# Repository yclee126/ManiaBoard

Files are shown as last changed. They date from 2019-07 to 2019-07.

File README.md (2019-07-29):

ManiaBoard (Osu! Keyboard)
==========================

A multi-functional gaming keyboard.

This has been for over a year before uploaded here(and everywhere else), and still WIP.

..For that reason, the code become really massive and finally filled up 99% of Pro Micro's storage. Ah, great.

Uses Arduino Pro Micro(Arduino Leonardo), WS2812B LED strip, Kalih Sockets.



Arduino's usb socket become loose over time with my intense gameplay and it caused occasional disconnection.
So I decided to use jumper wires instead until the next build. Yes, I'm lazy.

Features
--------

- 6 Keys + 2 Function keys
  - Simultaneous input up to 12 keys (Keyboard.h library modified)
  - 700Hz polling rate on average
  - Fast assembly-level pin reading
  - Fast debouncing
- Kalih Socket mount
  - Exchangeable Cherry keys
- Custom Keycaps
  - Lightweight and durable
- LED for each 6 keys
  - 4 different LED modes
  - Fast data transfer code
- KPS Calculation (Keys Per Second)
  - Up to 600 KPS
  - Fast integer time calculation
  - Max KPS indication
- Multiple Keymaps
  - With distinct LED color
- Built-in CUI Menu
  - Coder-friendly menu code
  - Change key mapping
  - Manage keymap slots
  - Multilingual menu (WIP)
  
Manual
------

1. Controls
```
          +----+----+
 (Arduino)| K1 | K2 | K7
+----+----+----+----+
| K3 | K4 | K5 | K6 | K8
+----+----+----+----+
```
- K1 - K6
  - Normal Keys
- K7 : Function Key 1
  - Short : K7
  - Long : Reset KPS display(K2 LED)
- K8 : Function Key 2
  - Short : K8
  - Long : Cycle keymaps
- K7 & K8
  - Short : Enter settings (open cmd or any text editor to print)
  - Long : Cycle LED mode

2. CUI Menu

Press K7 & K8 briefly to enter the setup.
Open cmd or any text editor program to print.
```
          +----+----+
 (Arduino)| UP |    |
+----+----+----+----+
|    | BK | DN | OK |
+----+----+----+----+
```
 - UP : Up
   - Move up from current menu
   - Increase value
 - DN : Down
   - Move down from current menu
   - Decrease value
 - BK : Back
   - Exit from current menu
   - Cancel operation (WIP)
 - OK : Ok
   - Go into selected menu
   - Confirm

Hold UP or DN for fast control.

3. LED Modes

The below map indicates which LED mode is set when it's cycling.

e.g. K6 LED is lit = Mode 4

Press and hold K7 & K8 to cycle.
```
          +----+----+
 (Arduino)|    |    |
+----+----+----+----+
| M1 | M2 | M3 | M4 |
+----+----+----+----+
```
 - Mode 1 : Bright Mode
   - *Colorful!*
     - Shows current KPS if not pressed
     - Shows invert of current color if pressed
     - K2 LED as Max KPS indicator
 - Mode 2 : Dark Mode
   - *Economic lighting.*
     - Shows nothing if not pressed (except for K2)
     - Shows current KPS if pressed
     - K2 LED as Max KPS indicator
 - Mode 3 : Mood Mode
   - *Just the feeling.*
     - Shows nothing if pressed or not (except for K2)
     - K2 LED as Max KPS indicator, but without the flash effect
 - Mode 4 : Stealth Mode
   - *Only you and your monitor.*
     - Shows nothing if pressed or not
     - But Max KPS is still being calculated (displayed on the settings menu)
   
LED shows current keymap color when it's cycling keymaps, regardless of which LED mode is set.

Parts
-----
 - 1 * Arduino Pro Micro
 - 6 * Kalih sockets
 - 6 * Transparent Cherry MX switches
 - 2 * Push buttons
 - 4 * M4 x 12.5mm Screws
   - Or in any length between 11.5mm and 13mm
 - 4 * M4 lock nuts
 - 1 * WS2812B LED strip (6 LEDs)
 - 1 * 330ohm Resistor
 - 1 * 100uF Capacitor (5V and up)
 - 2 * 10pin Pin header socket
 - 1 * PCB piece about size of arduino
 
 The screws and nuts can be gathered from 과학상자("Science Box") kit.

Schematic
---------
```
Dxx = Arduino digital Pin number
[KS] = Kalih Socket
[PB] = Push Button
330R = 330ohm resistor
100uF = 100uF capacitor

        GND
         |
D02-[KS]-+  //K1
	 |
D03-[KS]-+  //K2
	 |
D04-[KS]-+  //K3
	 |
D05-[KS]-+  //K4
	 |
D06-[KS]-+  //K5
	 |
D07-[KS]-+  //K6
	 |
D14-[PB]-+  //K7
	 |
D15-[PB]-+  //K8
         |
	 |  ############################
         +--gnd                        #
D10-330R----din  WS2812B Strip (6LEDs) #
         +--vin                        #
	 |  ############################
         |
	+5V--100uF--GND
```

TODO
----

- Complete the menu
- Optimize everything
- Make Thumb key for 5K maps
- Make right hand keyboard for 10K maps
- Find a better way to display KPS

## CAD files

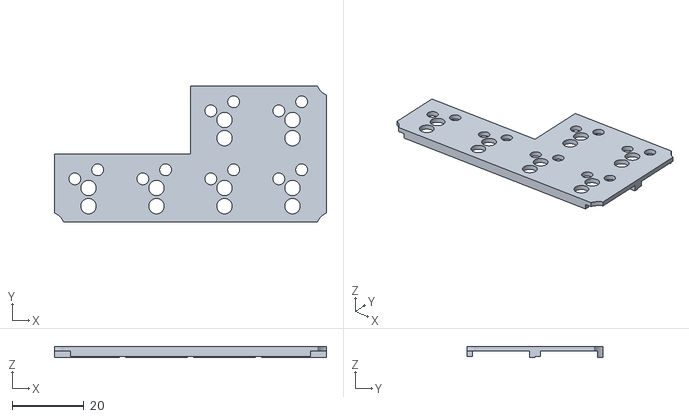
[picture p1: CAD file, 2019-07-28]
Model/frame.stl
76.0 x 38.0 x 3.15

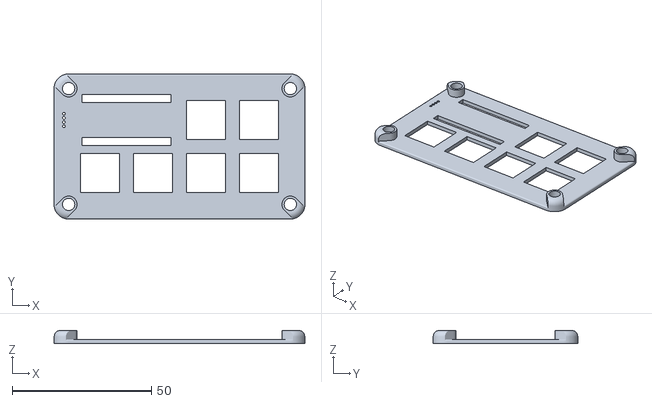
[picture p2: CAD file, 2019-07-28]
Model/upper.stl
90.1 x 52.1 x 4.70

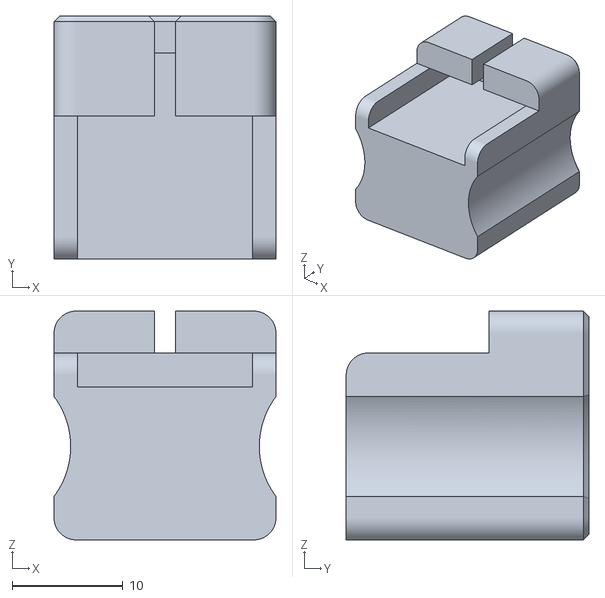
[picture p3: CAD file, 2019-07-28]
Model/Keycap_support_remove_bench.stl
20.0 x 21.9 x 20.6

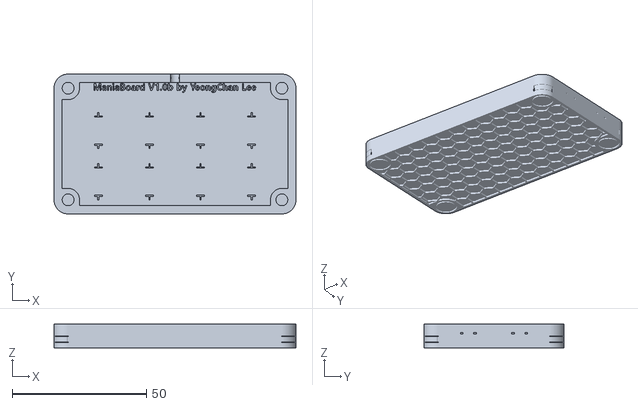
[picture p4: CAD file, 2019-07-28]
Model/body.stl
90.1 x 52.1 x 8.90

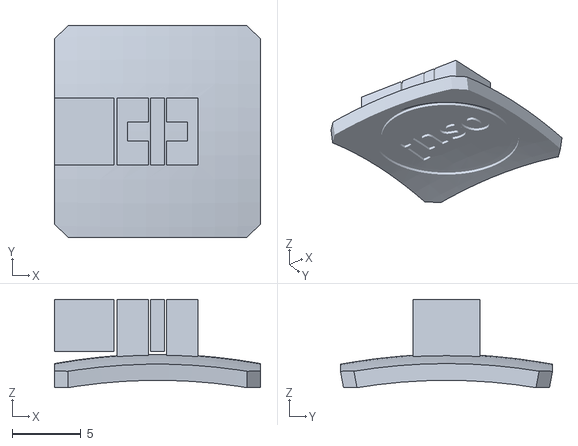
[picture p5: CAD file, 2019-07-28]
Model/Keycap.stl
15.0 x 15.4 x 6.44

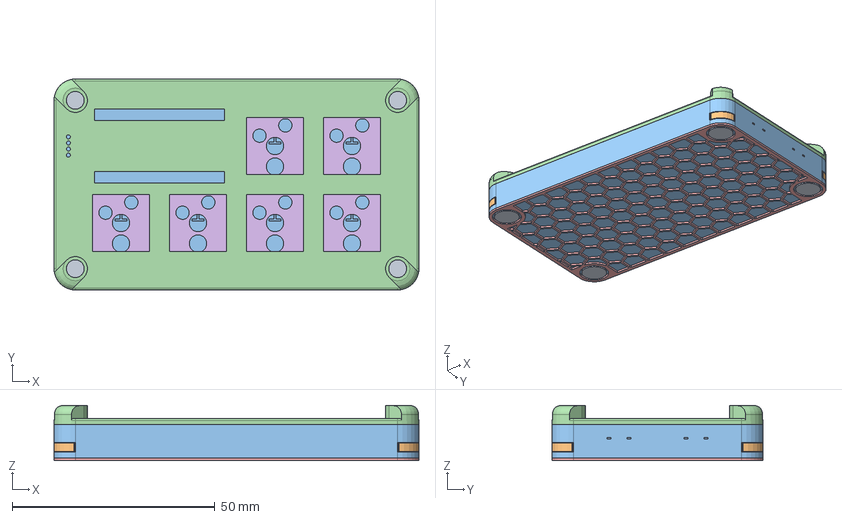
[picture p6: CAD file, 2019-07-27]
Model/ManiaBoard.FCStd
90.1 x 52.1 x 13.6 mm
Slip pad hole suport
nut support
Main body
upper
hex bottom001
Kalih and LED Frame

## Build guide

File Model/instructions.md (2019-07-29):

Print Settings
--------------

- 0.15mm initial layer height
- 0.15mm layer height
- 0.3mm nozzle size

Known defects
-------------

- The push button holes at the right side is too small

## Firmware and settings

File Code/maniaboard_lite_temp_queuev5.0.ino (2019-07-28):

// Created by yclee126 for maniaboard project V5.4
/*

  ===== CONTROLS =====
           +----+----+
  (Arduino)| K1 | K2 | K7
 +----+----+----+----+
 | K3 | K4 | K5 | K6 | K8
 +----+----+----+----+

 K7 short press : K7
 K7 long press : Reset kps display(K2 led)
 K8 short press : K8
 K8 long press : Cycle keymaps
 K7 & K8 short press : Enter settings (open notepad to print)
 K7 & K8 long press : Cycle led mode

*/

#include "Maniaboard.h"
#include "usb_hid_keys.h"
#include "EEPROM.h"

//#define DEBUGMODE

#define LED_PIN     10
#define NUM_LEDS    6

byte leds[NUM_LEDS][3] = {0,};// G R B
char indexChar = 'e'; //cycle this char between uppercase and lowercase if the code change has to be applied to the EEPROM

byte const keyCount = 8;
byte const slotLimit = 10; //Maximum slots (affects initGradient, key, mod)
byte slotCount = 5; //number of slots
byte slot = 0;
byte realKeyValue[2];
byte realModValue[2];
boolean enterSettings;

int dataAdr;
int indexAdr;

const byte strBufferSize = 200;
char strBuffer[strBufferSize]; // <=256
#define msg(stw) strlen(stw) < strBufferSize ? strcpy_P(strBuffer, PSTR(stw)) : strcpy_P(strBuffer, PSTR("**ERROR : The msg is too long! SKIPPED.")), typemsg()
//      |------| |---------------------------?--------------------------------:--------------------------------------------------------------------|  |-------|
//Still I can't understand why "PSTR("**ERROR" part only takes the program storage as a single line, since it's in #define it should take multiple times as msg() is used!!
//comma used in there makes two expression bond together, so msg("something") returns typemsg()

#define str(stw) strlen(stw) < strBufferSize ? strcpy_P(strBuffer, PSTR(stw)) : strcpy_P(strBuffer, PSTR("**ERROR : The str is too long! SKIPPED.")), typestr()

byte typeSpeedChar = 12; //12 : allow multiple keystrokes, 1: type one by one
boolean turboMode = false; // support repeating multiple key presses?
//cmd 한글출력시에는 typeSpeed = 0 같이 설정해야함!!
int spaceMod = 0;
byte typeSpeed = typeSpeedChar - 1;
boolean constTurboMode = turboMode;

byte keyShade[6] = {0,};
byte const gradientCount = 6;
byte ledMode = 0;
/*
 * 0 = Bright mode
 * 1 = Night mode (all off except for the kps indicator and pressed keys)
 * 2 = All off
 */

struct{
  byte r;
  byte g;
  byte b;
}gradient[gradientCount];

struct{
  byte r;
  byte g;
  byte b;
}initGradient[slotLimit];

// !bitRead(PIND, 3)// TX
// !bitRead(PIND, 2)// RX
// !bitRead(PIND, 1)// 02
// !bitRead(PIND, 0)// 03
// !bitRead(PIND, 4)// 04
// !bitRead(PINC, 6)// 05
// !bitRead(PIND, 7)// 06
// !bitRead(PINE, 6)// 07
// !bitRead(PINB, 4)// 08
// !bitRead(PINB, 5)// 09
// !bitRead(PINB, 6)// 10
// !bitRead(PINB, 2)// 16
// !bitRead(PINB, 3)// 14
// !bitRead(PINB, 1)// 15
// !bitRead(PINF, 7)// A0
// !bitRead(PINF, 6)// A1
// !bitRead(PINF, 5)// A2
// !bitRead(PINF, 4)// A3
/*
PORTX ->true = pullup or high, false = tristate or low
DDRX  ->true = output, false = input
PINX  ->pin reading value return
*/

#define KEY0INPUT !bitRead(PIND, 1)// 02
#define KEY1INPUT !bitRead(PIND, 0)// 03
#define KEY2INPUT !bitRead(PIND, 4)// 04
#define KEY3INPUT !bitRead(PINC, 6)// 05
#define KEY4INPUT !bitRead(PIND, 7)// 06
#define KEY5INPUT !bitRead(PINE, 6)// 07
#define FUNC0INPUT !bitRead(PINB, 3)// 14
#define FUNC1INPUT !bitRead(PINB, 1)// 15

//key pins
byte const pin[keyCount] = {2, 3, 4, 5, 6, 7, 14, 15};

byte key[slotLimit][keyCount] = {0,};
byte mod[slotLimit][keyCount] = {0,};
boolean keyState[3][keyCount] = {0,};

unsigned long prevTime = millis();
boolean ledPower = false;
char latch = 's'; //to prevent "new maxKps" effect triggering at startup
/*
 * 'm' = maxkps clear
 * 's' = slot change
 * 'l' = led mode change
 */
byte kps = 0;
byte kpsAdd = 0;
int timeQueue[100] = {0,};
byte numQueue[100] = {0,};
int writePointer = 0;
int readPointer = 0;
byte queueCount = 0;
struct{
  boolean init = true;
  byte kps;
  byte r;
  byte g;
  byte b;
}maxKps;

int queueTime = millis() & long(2047);

byte const additionalSpace = (keyCount+3) * slotLimit;

void setup() {

  pinMode(LED_PIN, OUTPUT);
  showLed();

  {//default setting
  //slot 1 //Osu! mode
  initGradient[0] = {40, 17, 12};
  key[0][0] = KEY_UP;
  mod[0][0] = 0;
  key[0][1] = KEY_ESC;
  mod[0][1] = 0;
  key[0][2] = KEY_F2;
  mod[0][2] = 0;
  key[0][3] = KEY_LEFT;
  mod[0][3] = 0;
  key[0][4] = KEY_DOWN;
  mod[0][4] = 0;
  key[0][5] = KEY_RIGHT;
  mod[0][5] = 0;
  key[0][6] = KEY_SPACE;
  mod[0][6] = 0;
  key[0][7] = KEY_F10;
  mod[0][7] = 0;
                               
  //slot 2 //Bonk.io, tagpro.gg mode + copypaste
  initGradient[1] = {40, 60, 60};
  key[1][0] = KEY_UP;
  mod[1][0] = 0;
  key[1][1] = KEY_ESC;
  mod[1][1] = 0;
  key[1][2] = KEY_X;
  mod[1][2] = 0;
  key[1][3] = KEY_LEFT;
  mod[1][3] = 0;
  key[1][4] = KEY_DOWN;
  mod[1][4] = 0;
  key[1][5] = KEY_RIGHT;
  mod[1][5] = 0;
  key[1][6] = KEY_V;
  mod[1][6] = KEY_MOD_LCTRL;
  key[1][7] = KEY_C;
  mod[1][7] = KEY_MOD_LCTRL;
                               
  //slot 3 //WASD mode
  initGradient[2] = {40, 80, 20};
  key[2][0] = KEY_W;
  mod[2][0] = 0;
  key[2][1] = KEY_ENTER;
  mod[2][1] = 0;
  key[2][2] = KEY_SPACE;
  mod[2][2] = 0;
  key[2][3] = KEY_A;
  mod[2][3] = 0;
  key[2][4] = KEY_S;
  mod[2][4] = 0;
  key[2][5] = KEY_D;
  mod[2][5] = 0;
  key[2][6] = KEY_EQUAL; //with mod enabled
  mod[2][6] = KEY_MOD_LSHIFT;
  key[2][7] = KEY_MINUS;
  mod[2][7] = 0;
                               
  //slot 4 //undertale mode
  initGradient[3] = {40, 1, 1};
  key[3][0] = KEY_UP;
  mod[3][0] = 0;
  key[3][1] = KEY_X;
  mod[3][1] = 0;
  key[3][2] = KEY_Z;
  mod[3][2] = 0;
  key[3][3] = KEY_LEFT;
  mod[3][3] = 0;
  key[3][4] = KEY_DOWN;
  mod[3][4] = 0;
  key[3][5] = KEY_RIGHT;
  mod[3][5] = 0;
  key[3][6] = KEY_ESC;
  mod[3][6] = 0;
  key[3][7] = KEY_C;
  mod[3][7] = 0;
                               
  //slot 5 //test mode
  initGradient[4] = {100, 20, 10};
  key[4][0] = 0;
  mod[4][0] = 0;
  key[4][1] = 0;
  mod[4][1] = 0;
  key[4][2] = 0;
  mod[4][2] = 0;
  key[4][3] = 0;
  mod[4][3] = 0;
  key[4][4] = 0;
  mod[4][4] = 0;
  key[4][5] = 0;
  mod[4][5] = 0;
  key[4][6] = 0;
  mod[4][6] = 0;
  key[4][7] = 0;
  mod[4][7] = 0;
  }
  
  byte full = 100;
  
  gradient[0].r = initGradient[0].r;
  gradient[0].g = initGradient[0].g;
  gradient[0].b = initGradient[0].b;
  gradient[1] = {0, full, 0};
  gradient[2] = {full, full , 0};
  gradient[3] = {255, 103, 154};
  gradient[4] = {full, 0, full};
  gradient[5] = {255, 0, 0};
  
  if(checkEEPROM(indexChar)){ //the data is valid
    leds[1][1] = 200; //Green
    showLed();
    delay(500);
    ledMode = EEPROM.read(indexAdr+1);
    for(byte i = 0; i < slotLimit; i++){
      for(byte k = 0; k < keyCount; k++){
        key[i][k] = EEPROM.read( dataAdr + k + keyCount*0 + i*(keyCount*2 + 3) );
        mod[i][k] = EEPROM.read( dataAdr + k + keyCount*1 + i*(keyCount*2 + 3) );
      }
      initGradient[i].r = EEPROM.read( dataAdr + keyCount*2 + 0 + i*(keyCount*2 + 3) );
      initGradient[i].g = EEPROM.read( dataAdr + keyCount*2 + 1 + i*(keyCount*2 + 3) );
      initGradient[i].b = EEPROM.read( dataAdr + keyCount*2 + 2 + i*(keyCount*2 + 3) );
    }
  }
  else{ //invalid data, writing new data
    leds[1][0] = 200; //Red
    showLed();
    delay(500);
    EEPROM.update(indexAdr+1, ledMode);
    for (int i = 0 ; i < EEPROM.length() ; i++) {
      EEPROM.update(i, 0);
      analogRead(A1);
    }
    randomSeed(analogRead(A1));
    indexAdr = random(0,EEPROM.length()-(keyCount*slotLimit*2) );
    dataAdr = indexAdr + 2;
    EEPROM.update(indexAdr, indexChar);
    for(byte i = 0; i < slotLimit; i++){
      writeKeyMod(i);
      writeInitGradient(i);
    }
  }
  
  //used when the function key disabled as a normal key
  backupFuncKeys();
  
  for(byte i = 0; i < keyCount; i++){
    pinMode(pin[i], INPUT_PULLUP);
  }
  
  pinMode(A3, OUTPUT);

  maxKps.kps = 0;
  maxKps.r = initGradient[0].r;
  maxKps.g = initGradient[0].g;
  maxKps.b = initGradient[0].b;
  
  Keyboard.begin();
  #ifdef DEBUGMODE
  Serial.begin(115200);
  #endif
  
}

// Polling rate must be measured as double of A3's output!!

void loop() {
  
  keyState[0][0] = KEY0INPUT;
  if(keyState[0][0] == keyState[1][0]) if(keyState[2][0] == !keyState[0][0]) keyState[0][0] = !keyState[0][0];
  keyState[0][1] = KEY1INPUT;
  if(keyState[0][1] == keyState[1][1]) if(keyState[2][1] == !keyState[0][1]) keyState[0][1] = !keyState[0][1];
  keyState[0][2] = KEY2INPUT;
  if(keyState[0][2] == keyState[1][2]) if(keyState[2][2] == !keyState[0][2]) keyState[0][2] = !keyState[0][2];
  keyState[0][3] = KEY3INPUT;
  if(keyState[0][3] == keyState[1][3]) if(keyState[2][3] == !keyState[0][3]) keyState[0][3] = !keyState[0][3];
  keyState[0][4] = KEY4INPUT;
  if(keyState[0][4] == keyState[1][4]) if(keyState[2][4] == !keyState[0][4]) keyState[0][4] = !keyState[0][4];
  keyState[0][5] = KEY5INPUT;
  if(keyState[0][5] == keyState[1][5]) if(keyState[2][5] == !keyState[0][5]) keyState[0][5] = !keyState[0][5];
  keyState[0][6] = FUNC0INPUT;
  if(keyState[0][6] == keyState[1][6]) if(keyState[2][6] == !keyState[0][6]) keyState[0][6] = !keyState[0][6];
  keyState[0][7] = FUNC1INPUT;
  if(keyState[0][7] == keyState[1][7]) if(keyState[2][7] == !keyState[0][7]) keyState[0][7] = !keyState[0][7];
  Keyboard.packet(
    mod[slot][0]*keyState[0][0] | mod[slot][1]*keyState[0][1] | mod[slot][2]*keyState[0][2] | mod[slot][3]*keyState[0][3] | mod[slot][4]*keyState[0][4] | mod[slot][5]*keyState[0][5] | mod[slot][6]*keyState[0][6] | mod[slot][7]*keyState[0][7],
    key[slot][0]*keyState[0][0],
    key[slot][1]*keyState[0][1],
    key[slot][2]*keyState[0][2],
    key[slot][3]*keyState[0][3],
    key[slot][4]*keyState[0][4],
    key[slot][5]*keyState[0][5],
    key[slot][6]*keyState[0][6],
    key[slot][7]*keyState[0][7],
    0,
    0,
    0,
    0
  );
  
  checkFunc(0);                                                                                                                                                               

  PORTF ^= B00010000;
  
  keyState[1][0] = KEY0INPUT;
  if(keyState[1][0] == keyState[2][0]) if(keyState[0][0] == !keyState[1][0]) keyState[1][0] = !keyState[1][0];
  keyState[1][1] = KEY1INPUT;
  if(keyState[1][1] == keyState[2][1]) if(keyState[0][1] == !keyState[1][1]) keyState[1][1] = !keyState[1][1];
  keyState[1][2] = KEY2INPUT;
  if(keyState[1][2] == keyState[2][2]) if(keyState[0][2] == !keyState[1][2]) keyState[1][2] = !keyState[1][2];
  keyState[1][3] = KEY3INPUT;
  if(keyState[1][3] == keyState[2][3]) if(keyState[0][3] == !keyState[1][3]) keyState[1][3] = !keyState[1][3];
  keyState[1][4] = KEY4INPUT;
  if(keyState[1][4] == keyState[2][4]) if(keyState[0][4] == !keyState[1][4]) keyState[1][4] = !keyState[1][4];
  keyState[1][5] = KEY5INPUT;
  if(keyState[1][5] == keyState[2][5]) if(keyState[0][5] == !keyState[1][5]) keyState[1][5] = !keyState[1][5];
  keyState[1][6] = FUNC0INPUT;
  if(keyState[1][6] == keyState[2][6]) if(keyState[0][6] == !keyState[1][6]) keyState[1][6] = !keyState[1][6];
  keyState[1][7] = FUNC1INPUT;
  if(keyState[1][7] == keyState[2][7]) if(keyState[0][7] == !keyState[1][7]) keyState[1][7] = !keyState[1][7];
  Keyboard.packet(
    mod[slot][0]*keyState[1][0] | mod[slot][1]*keyState[1][1] | mod[slot][2]*keyState[1][2] | mod[slot][3]*keyState[1][3] | mod[slot][4]*keyState[1][4] | mod[slot][5]*keyState[1][5] | mod[slot][6]*keyState[1][6] | mod[slot][7]*keyState[1][7],
    key[slot][0]*keyState[1][0],
    key[slot][1]*keyState[1][1],
    key[slot][2]*keyState[1][2],
    key[slot][3]*keyState[1][3],
    key[slot][4]*keyState[1][4],
    key[slot][5]*keyState[1][5],
    key[slot][6]*keyState[1][6],
    key[slot][7]*keyState[1][7],
    0,
    0,
    0,
    0
  );
  
  checkFunc(1);

  PORTF ^= B00010000;
  
  keyState[2][0] = KEY0INPUT;
  if(keyState[2][0] == keyState[0][0]) if(keyState[1][0] == !keyState[2][0]) keyState[2][0] = !keyState[2][0];
  keyState[2][1] = KEY1INPUT;
  if(keyState[2][1] == keyState[0][1]) if(keyState[1][1] == !keyState[2][1]) keyState[2][1] = !keyState[2][1];
  keyState[2][2] = KEY2INPUT;
  if(keyState[2][2] == keyState[0][2]) if(keyState[1][2] == !keyState[2][2]) keyState[2][2] = !keyState[2][2];
  keyState[2][3] = KEY3INPUT;
  if(keyState[2][3] == keyState[0][3]) if(keyState[1][3] == !keyState[2][3]) keyState[2][3] = !keyState[2][3];
  keyState[2][4] = KEY4INPUT;
  if(keyState[2][4] == keyState[0][4]) if(keyState[1][4] == !keyState[2][4]) keyState[2][4] = !keyState[2][4];
  keyState[2][5] = KEY5INPUT;
  if(keyState[2][5] == keyState[0][5]) if(keyState[1][5] == !keyState[2][5]) keyState[2][5] = !keyState[2][5];
  keyState[2][6] = FUNC0INPUT;
  if(keyState[2][6] == keyState[0][6]) if(keyState[1][6] == !keyState[2][6]) keyState[2][6] = !keyState[2][6];
  keyState[2][7] = FUNC1INPUT;
  if(keyState[2][7] == keyState[0][7]) if(keyState[1][7] == !keyState[2][7]) keyState[2][7] = !keyState[2][7];
  Keyboard.packet(
    mod[slot][0]*keyState[2][0] | mod[slot][1]*keyState[2][1] | mod[slot][2]*keyState[2][2] | mod[slot][3]*keyState[2][3] | mod[slot][4]*keyState[2][4] | mod[slot][5]*keyState[2][5] | mod[slot][6]*keyState[2][6] | mod[slot][7]*keyState[2][7],
    key[slot][0]*keyState[2][0],
    key[slot][1]*keyState[2][1],
    key[slot][2]*keyState[2][2],
    key[slot][3]*keyState[2][3],
    key[slot][4]*keyState[2][4],
    key[slot][5]*keyState[2][5],
    key[slot][6]*keyState[2][6],
    key[slot][7]*keyState[2][7],
    0,
    0,
    0,
    0
  );
  
  checkFunc(2);

  PORTF ^= B00010000;
  
}

void writeKeyMod(byte i){
  for(byte k = 0; k < keyCount; k++){
    EEPROM.update(dataAdr + k + keyCount*0 + i*(keyCount*2 + 3), key[i][k]);
    EEPROM.update(dataAdr + k + keyCount*1 + i*(keyCount*2 + 3), mod[i][k]);
  }
}

void writeInitGradient(byte i){
  EEPROM.update(dataAdr + keyCount*2 + 0 + i*(keyCount*2 + 3), initGradient[i].r);
  EEPROM.update(dataAdr + keyCount*2 + 1 + i*(keyCount*2 + 3), initGradient[i].g);
  EEPROM.update(dataAdr + keyCount*2 + 2 + i*(keyCount*2 + 3), initGradient[i].b);
}

//byte skps;

void checkFunc(byte num){
  
  kpsAdd = 0;
  byte prevNum = (num+2)%3;
  for(byte i = 0; i < 6; i++){ //does not include function keys
    if(keyState[prevNum][i] == false && keyState[num][i] == true) kpsAdd++;
  }

  queueTime = millis() & long(2047);

  writePointer %= 100;
  readPointer %= 100;
  
  if(kpsAdd != 0){ //add kps info to the queue
    timeQueue[writePointer] = queueTime;
    numQueue[writePointer] = kpsAdd;
    
    kps += kpsAdd;
    writePointer++;
    queueCount++;
  }
  
  //while(1){ //remove kps info from the queue
    int diff = queueTime - timeQueue[readPointer];
    
    if( ((diff > 0 && diff > 999) || (diff < 0 && diff > -1049)) && queueCount != 0 ){
      kps -= numQueue[readPointer];
      readPointer++;
      queueCount--;
    }
  //  else break;
  //} //somehow while() causes bug. but I think it's correct, so I left that code into remark.

  byte r = 255;
  byte g = 0;
  byte b = 0; 

  byte shadeLevel = 4;
  byte gCount = 6; //number of gradients
  byte gNum = kps/shadeLevel;
  byte cKps = kps%shadeLevel;
  if(gNum < gCount-1){
    r = map(cKps, 0, shadeLevel, gradient[gNum].r, gradient[gNum+1].r);
    g = map(cKps, 0, shadeLevel, gradient[gNum].g, gradient[gNum+1].g);
    b = map(cKps, 0, shadeLevel, gradient[gNum].b, gradient[gNum+1].b);
  }
  else{
    r = gradient[gCount-1].r;
    g = gradient[gCount-1].g;
    b = gradient[gCount-1].b;
  }
  
  byte keyShadeLevel = 80; //the shade of color when the key is pressed. (big number means longer glowing time)
  struct{
    byte r = 200;
    byte g = 200;
    byte b = 200;
  }pressedcolor;
  
  if(maxKps.kps < kps || maxKps.init == true){
    if(latch != 's'){
      keyShade[1] = keyShadeLevel;
    }
    maxKps.init = false;
    maxKps.kps = kps;
    maxKps.r = r;
    maxKps.g = g;
    maxKps.b = b;
  }

  if(latch == 's'){ //////////////////////////////////////NEED OPTIMIZATION
    byte gNum = maxKps.kps/shadeLevel;
    byte cKps = maxKps.kps%shadeLevel;
    if(gNum < gCount-1){
      maxKps.r = map(cKps, 0, shadeLevel, gradient[gNum].r, gradient[gNum+1].r);
      maxKps.g = map(cKps, 0, shadeLevel, gradient[gNum].g, gradient[gNum+1].g);
      maxKps.b = map(cKps, 0, shadeLevel, gradient[gNum].b, gradient[gNum+1].b);
    }
    else{
      maxKps.r = gradient[gCount-1].r;
      maxKps.g = gradient[gCount-1].g;
      maxKps.b = gradient[gCount-1].b;
    }
    
    if(ledMode == 1 || ledMode == 2){ //show shadecolor
      for(byte i = 0; i < 6; i++){
        keyShade[i] = keyShadeLevel;
      }
    }
    else if(ledMode == 3){
      keyShade[0] = keyShadeLevel;
    }
  }

  switch(ledMode){
    
    case 0:
      for(byte i = 0; i < 6; i++){
        if(keyShade[i] != 0) keyShade[i] --; //restore to original color over time
        if(keyState[num][i]) keyShade[i] = keyShadeLevel; //if pressed
        
        if(i == 1){ //kps indicator
          leds[i][0] = map(keyShade[i], 0, keyShadeLevel, maxKps.r, 255-r);
          leds[i][1] = map(keyShade[i], 0, keyShadeLevel, maxKps.g, 255-g);
          leds[i][2] = map(keyShade[i], 0, keyShadeLevel, maxKps.b, 255-b);
        }
        else{ //other keys
          leds[i][0] = map(keyShade[i], 0, keyShadeLevel, r, 255-r);
          leds[i][1] = map(keyShade[i], 0, keyShadeLevel, g, 255-g);
          leds[i][2] = map(keyShade[i], 0, keyShadeLevel, b, 255-b);
        }
      }
      break;
      
    case 1:
      for(byte i = 0; i < 6; i++){
        if(keyShade[i] != 0) keyShade[i] --; //restore to original color over time
        if(keyState[num][i]) keyShade[i] = keyShadeLevel; //if pressed
        
        if(i == 1){ //kps indicator
          leds[i][0] = map(keyShade[i], 0, keyShadeLevel, maxKps.r, 255-r);
          leds[i][1] = map(keyShade[i], 0, keyShadeLevel, maxKps.g, 255-g);
          leds[i][2] = map(keyShade[i], 0, keyShadeLevel, maxKps.b, 255-b);
        }
        else{ //other keys
          leds[i][0] = map(keyShade[i], 0, keyShadeLevel, 0, r);
          leds[i][1] = map(keyShade[i], 0, keyShadeLevel, 0, g);
          leds[i][2] = map(keyShade[i], 0, keyShadeLevel, 0, b);
        }
      }
      break;
    
    case 2:
      for(byte i = 0; i < 6; i++){
        if(keyShade[i] != 0) keyShade[i] --; //restore to original color over time except for kps indicator (not smooth cause running out of code storage)
                                             //should've used 'm' latch to trigger flashing effect and 3 map() func.
        if(i == 1){
          leds[1][0] = maxKps.r;
          leds[1][1] = maxKps.g;
          leds[1][2] = maxKps.b;
        }
        else{
          leds[i][0] = map(keyShade[i], 0, keyShadeLevel, 0, r);
          leds[i][1] = map(keyShade[i], 0, keyShadeLevel, 0, g);
          leds[i][2] = map(keyShade[i], 0, keyShadeLevel, 0, b);
        }
      }
      break;

    case 3:
      for(byte i = 0; i < 6; i++){
        if(keyShade[0] != 0) keyShade[0] --; //restore to original color over time (using only keyShade[0])
        leds[i][0] = map(keyShade[0], 0, keyShadeLevel, 0, r);
        leds[i][1] = map(keyShade[0], 0, keyShadeLevel, 0, g);
        leds[i][2] = map(keyShade[0], 0, keyShadeLevel, 0, b);
      }
      break;
      
  }
  if(latch == 'l'){ //indicate ledMode by K3-K6
    for(byte i = 2; i < 6; i++){
      if( i == (ledMode+2) ){
        leds[i][0] = 255-r;
        leds[i][1] = 255-g;
        leds[i][2] = 255-b;
      }
      else{
        leds[i][0] = 0;
        leds[i][1] = 0;
        leds[i][2] = 0;
      }
    }
  }
  showLed();
  
  if(keyState[num][7] == true || keyState[num][6] == true){
    
    if(latch == 0 && keyState[num][7] == true && keyState[num][6] == true){ //open settings later
      enterSettings = true;
      Serial.print("Latch:");
      Serial.println(latch, DEC);
    }
    
    if(millis() - prevTime > 400){ //long press trigger
      enterSettings = false;
    
      if( (latch == 0 || latch == 'l') && keyState[num][7] == true && keyState[num][6] == true){ //change LED behavior
        disableFuncKeys();
        if(latch == 0){
          latch = 'l';
        }
        ledMode ++;
        ledMode %= 4;
        EEPROM.update(indexAdr+1, ledMode);
        prevTime = millis();
      }
        
      else if( (latch == 0 || latch == 's') && keyState[num][7] == true){ // swap keymap
        if(latch == 0){
          latch = 's';
        }
        restoreFuncKeys();
        slot++;
        slot %= slotCount;
        backupFuncKeys();
        disableFuncKeys();
        gradient[0].r = initGradient[slot].r;
        gradient[0].g = initGradient[slot].g;
        gradient[0].b = initGradient[slot].b;
        //maxKps.init = true; //de-rem it if you like it
        keyState[num][6] = false; //to not trigger reset max kps
        prevTime = millis();
      }
      
      else if( (latch == 0 || latch == 'm') && keyState[num][6] == true){ // reset max kps
        if(latch == 0){
          backupFuncKeys();
          disableFuncKeys();
          latch = 'm';
          maxKps.init = true;
        }
        prevTime = millis();
      }
      
    }
  }
  else{
    if(latch){
      restoreFuncKeys();
      keyState[num][6] = false;
      keyState[num][7] = false;
      latch = 0;
    }
    Serial.println(enterSettings, BIN);
    if(enterSettings){ //open settings
      settings();
      keyState[num][6] = false;
      keyState[num][7] = false;
      enterSettings = false;
    }
    prevTime = millis();
  }
  //delay(1000);
}

void backupFuncKeys(){
  realKeyValue[0] = key[slot][6];
  realModValue[0] = mod[slot][6];
  realKeyValue[1] = key[slot][7];
  realModValue[1] = mod[slot][7];
}

void disableFuncKeys(){
  key[slot][6] = 0;
  mod[slot][6] = 0;
  key[slot][7] = 0;
  mod[slot][7] = 0;
}

void restoreFuncKeys(){
  key[slot][6] = realKeyValue[0];
  mod[slot][6] = realModValue[0];
  key[slot][7] = realKeyValue[1];
  mod[slot][7] = realModValue[1];
}
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

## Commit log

2019-07-27 CAD files
    [ManiaBoard.FCStd]
2019-07-27 Add files via upload
    REM : Make a folder first THEN upload files
    [ManiaBoard.FCStd]
2019-07-27 Delete ManiaBoard.FCStd
    moving to the model folder
    [ManiaBoard.FCStd]
2019-07-28 model files
    [Keycap.stl, Keycap_support_remove_bench.stl, body.stl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]
